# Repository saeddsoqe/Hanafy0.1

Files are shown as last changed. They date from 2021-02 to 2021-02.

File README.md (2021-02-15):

# Hanafy 0.1

H 0.1
The H series is an open-source educational programmable circuit board powered by regular alkaline batteries. The H series is a safe, easy-to-use, platform for building projects in school at home or for fun

In this repo:
Schematic 
Layout
3D model
Bill Of Material
Graber file

Features
Version: H-0.1
ARM architecture.
ESP32 Dev Board. Dual core processor.  
Dimensions: 7.4cm * 7.2cm * 2cm

Built-in modules:
LDR (light sensor)
Push button *4
I/O pins *10
ON/OFF switch
RGB 
4 push buttons

Supports:
DC motor *2
Stepper motor *1

Power Supply: 
1.5V *4

Development environment:Block programming

Release date:March 2021
    Autodesk Eagle for schematic and layout design, and Fusion 360 for the 3D design.  

// Extra info
Supports:
  Wifi*
  Bluetooth*
  Servo motors 1
  They are connected with a pull up resistor*
version02: 
IoT capabilites

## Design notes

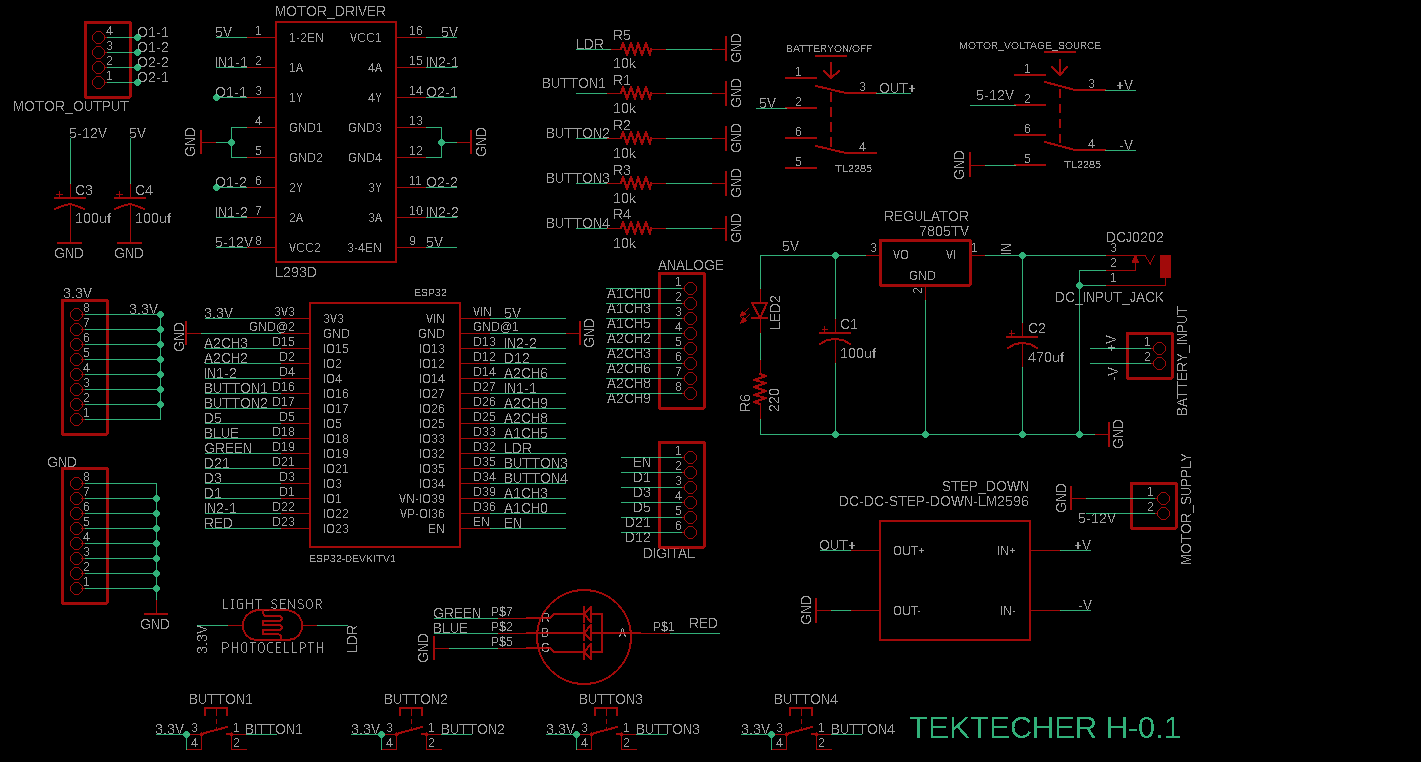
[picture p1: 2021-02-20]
PICs/schamatic.png

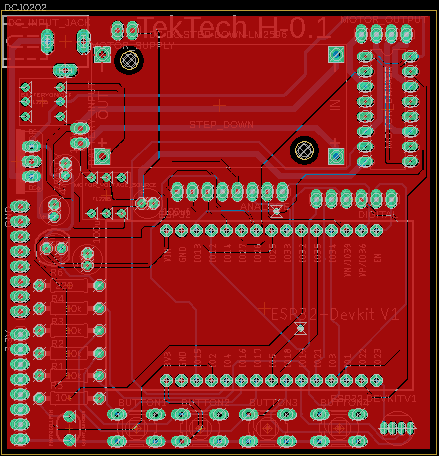
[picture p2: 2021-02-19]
PICs/fullLayout01.png

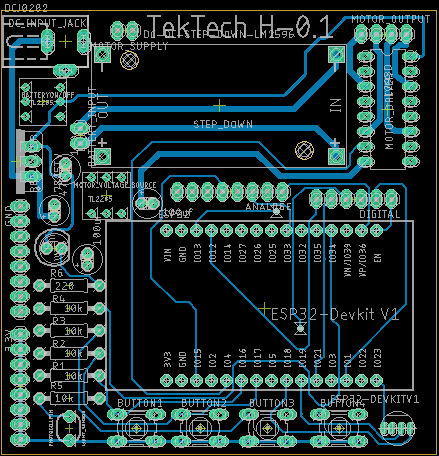
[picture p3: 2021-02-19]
PICs/fullLayout02.png

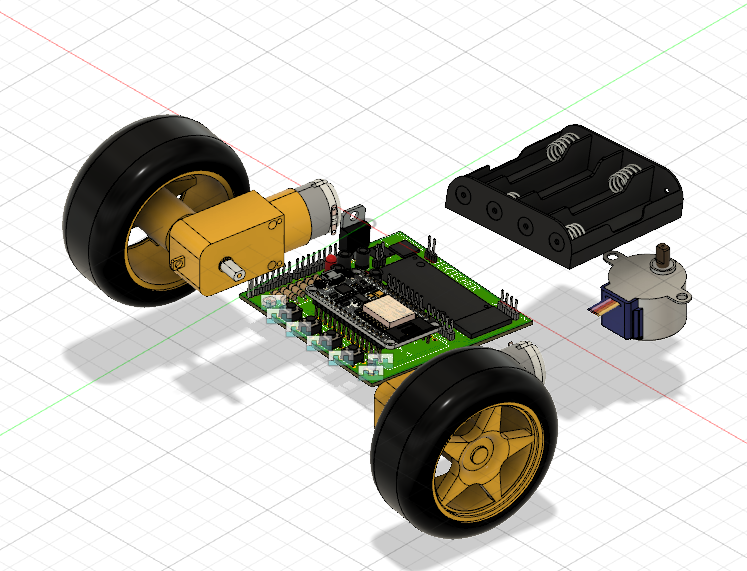
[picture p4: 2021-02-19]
PICs/Capture.PNG

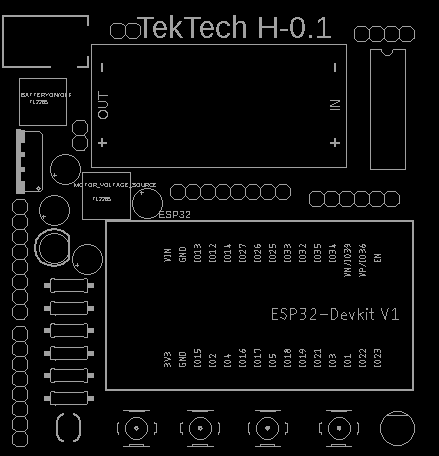
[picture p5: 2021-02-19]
PICs/LAYOUT_v02.png

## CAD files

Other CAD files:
Board/3D Model/assembly v3.f3z

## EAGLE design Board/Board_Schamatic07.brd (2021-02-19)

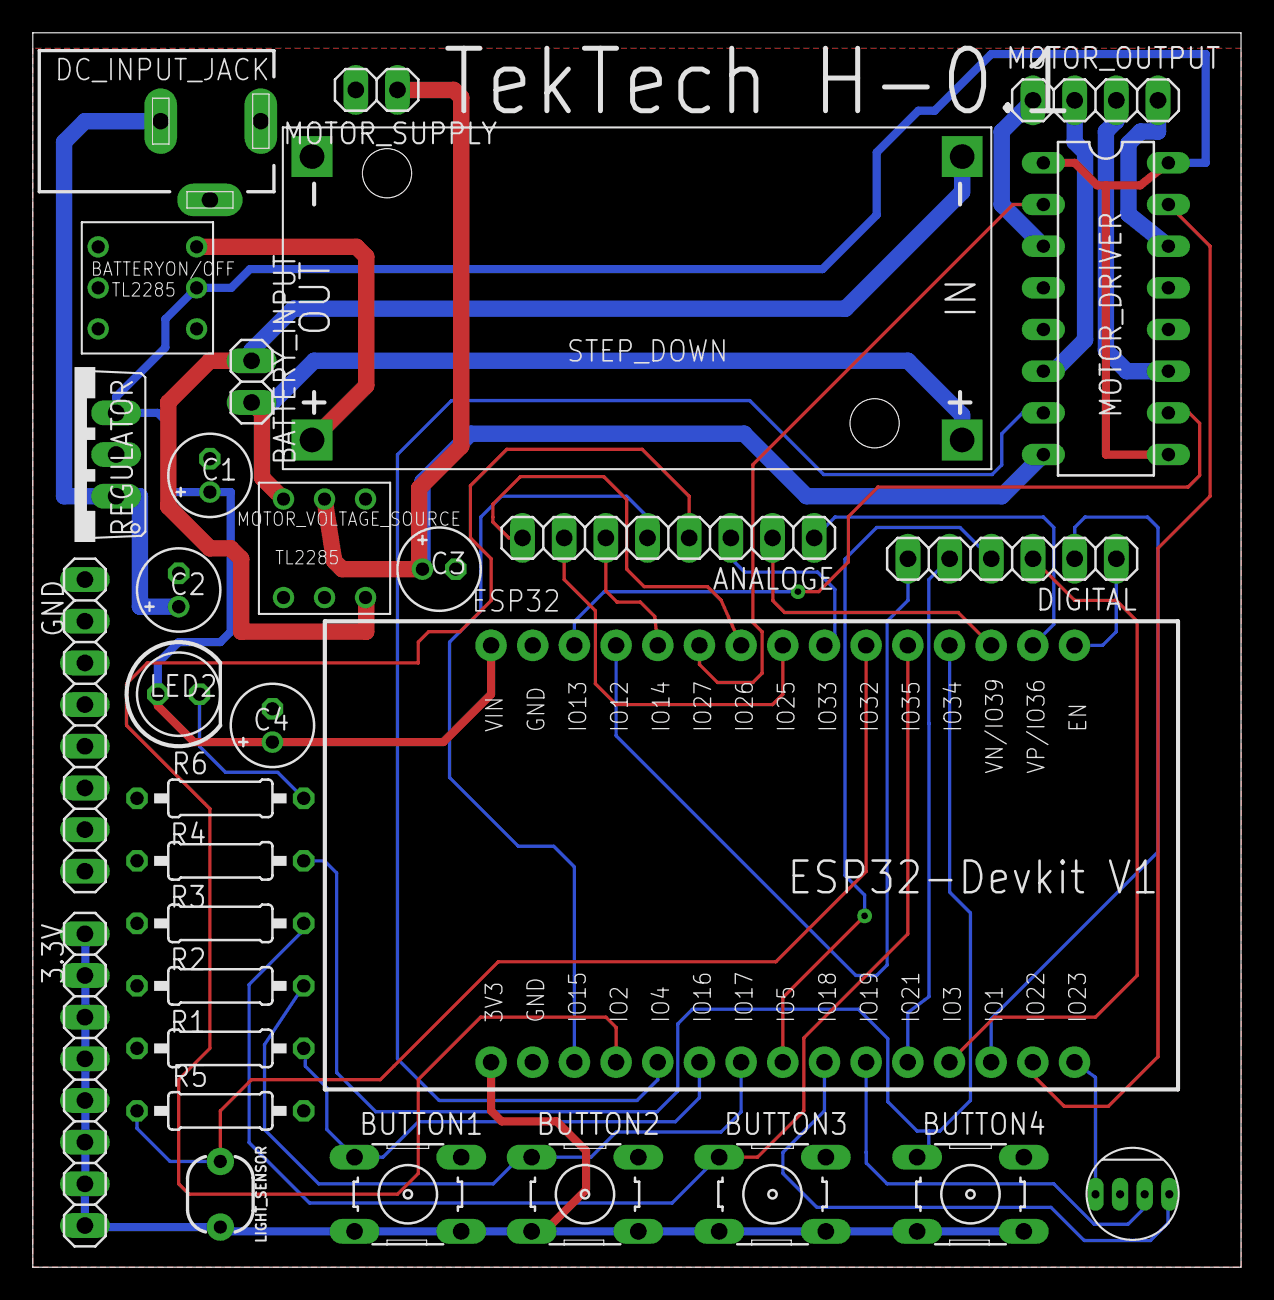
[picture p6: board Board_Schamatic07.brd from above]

Board: 2 copper layers, 73.6 x 75.2 mm, 31 parts (0 on the bottom side), 39 nets.

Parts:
3.3V: 1X08
ANALOGE: 1X08
BATTERYON/OFF: TL2285; TL2285_PCB
BATTERY_INPUT: 1X02
BUTTON1, BUTTON2, BUTTON3, BUTTON4: B3F-10XX
C1, C3, C4: 100uf; E2-5
C2: 470uf; E2-5
DC_INPUT_JACK: DCJ0202
DIGITAL: 1X06
ESP32: ESP32DEVKITV1; ESP32-DEVKITV1
GND: 1X08
LED2: LED5MM
LIGHT_SENSOR: PHOTOCELLPTH; PHOTOCELL
MOTOR_DRIVER: L293D; DIL16
MOTOR_OUTPUT: 1X04
MOTOR_SUPPLY: 1X02
MOTOR_VOLTAGE_SOURCE: TL2285; TL2285_PCB
R1, R2, R3, R4, R5: 10k; 0207/10
R6: 220; 0207/10
REGULATOR: 7805TV; TO220V
RGB: LED-4_PIN
STEP_DOWN: DC-DC-STEP-DOWN-LM2596

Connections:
3.3V: 3.3V.1, 3.3V.2, 3.3V.3, 3.3V.4, 3.3V.5, 3.3V.6, 3.3V.7, 3.3V.8, BUTTON1.3, BUTTON1.4, BUTTON2.3, BUTTON2.4, BUTTON3.3, BUTTON3.4, BUTTON4.3, BUTTON4.4, ESP32.3V3, LIGHT_SENSOR.2
5-12V: C3.+, MOTOR_DRIVER.8, MOTOR_SUPPLY.2, MOTOR_VOLTAGE_SOURCE.2
5V: BATTERYON/OFF.2, C1.+, C4.+, ESP32.VIN, LED2.A, MOTOR_DRIVER.1, MOTOR_DRIVER.9, MOTOR_DRIVER.16, REGULATOR.3
+V: BATTERY_INPUT.1, MOTOR_VOLTAGE_SOURCE.3, STEP_DOWN.IN+
-V: BATTERY_INPUT.2, MOTOR_VOLTAGE_SOURCE.4, STEP_DOWN.IN-
A1CH0: ANALOGE.1, ESP32.D36
A1CH3: ANALOGE.2, ESP32.D39
A1CH5: ANALOGE.3, ESP32.D33
A2CH2: ANALOGE.4, ESP32.D2
A2CH3: ANALOGE.5, ESP32.D15
A2CH6: ANALOGE.6, ESP32.D14
A2CH8: ANALOGE.7, ESP32.D25
A2CH9: ANALOGE.8, ESP32.D26
BLUE: ESP32.D18, RGB.P$2
D1: DIGITAL.2, ESP32.D1
D3: DIGITAL.3, ESP32.D3
D5: DIGITAL.4, ESP32.D5
D12: DIGITAL.6, ESP32.D12
D21: DIGITAL.5, ESP32.D21
EN: DIGITAL.1, ESP32.EN
GND: C1.-, C2.-, C3.-, C4.-, DC_INPUT_JACK.1, DC_INPUT_JACK.2, ESP32.GND@1, ESP32.GND@2, GND.1, GND.2, GND.3, GND.4, GND.5, GND.6, GND.7, GND.8, MOTOR_DRIVER.4, MOTOR_DRIVER.5, MOTOR_DRIVER.12, MOTOR_DRIVER.13, MOTOR_SUPPLY.1, MOTOR_VOLTAGE_SOURCE.5, R1.2, R2.2, R3.2, R4.2, R5.2, R6.1, REGULATOR.2, RGB.P$5, STEP_DOWN.OUT-
GREEN: ESP32.D19, RGB.P$7
IN: C2.+, DC_INPUT_JACK.3, REGULATOR.1
IN1-1: ESP32.D27, MOTOR_DRIVER.2
IN1-2: ESP32.D4, MOTOR_DRIVER.7
IN2-1: ESP32.D22, MOTOR_DRIVER.15
IN2-2: ESP32.D13, MOTOR_DRIVER.10
unnamed: BATTERYON/OFF.3, STEP_DOWN.OUT+
unnamed: LED2.K, R6.2
unnamed: BUTTON3.1, ESP32.D35, R3.1
unnamed: BUTTON4.1, ESP32.D34, R4.1
unnamed: ESP32.D32, LIGHT_SENSOR.1, R5.1
unnamed: BUTTON1.1, ESP32.D16, R1.1
unnamed: BUTTON2.1, ESP32.D17, R2.1
O1-1: MOTOR_DRIVER.3, MOTOR_OUTPUT.4
O1-2: MOTOR_DRIVER.6, MOTOR_OUTPUT.3
O2-1: MOTOR_DRIVER.14, MOTOR_OUTPUT.1
O2-2: MOTOR_DRIVER.11, MOTOR_OUTPUT.2
RED: ESP32.D23, RGB.P$1

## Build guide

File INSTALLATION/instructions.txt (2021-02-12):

Download and install Microblocks. 
------------------------------------------------------------------------
FOR WINDOWS 
1- Run microBlocks setup.exe 
2- MicroBlocks can be used in your browser 
https://microblocks.fun/run/microblocks.html
3- Or you cand download it as extenstion for Chrome from here 
https://chrome.google.com/webstore/detail/microblocks/cbmcbhgijipgdmlnieolilhghfmnngbb?authuser=0 
4-On some systems, you may need to install a serial driver. 
Depending on the USB-serial chip on your board you may need one of these:
   1-(CH340G driver) https://github.com/nodemcu/nodemcu-devkit/tree/master/Drivers 
   2-(Silcon Labs CP210x driver)https://www.silabs.com/products/development-tools/software/usb-to-uart-bridge-vcp-drivers

For MAC
On Mac OS, you need to confirm that MicroBlocks was downloaded from the internet the first time you run it.
1-Right-click on MicroBlocks.app and select "Open" from the menu:
*put photo*
2-Then click the "Open" button in the confirmation dialog:
*put photo* 
3-The dialog box will close. Now, double-click on MicroBlocks.app to open it.

FOR LINUX
On Linux systems, users don’t have access to the USB serial port by default. To fix that, just add yourself to 
the "dialout" group by running this in a terminal:
sudo usermod -G dialout -a `whoami`
Log out and back in to make the change take effect. You should see "dialout" when you list your groups.

Installing MicroBlocks Firmware
--------------------------------------------------------------------
To install the MicroBlocks firmware on an TIK TECH Board,
1-launch MicroBlocks and plug in the board. From the MicroBlocks (gear) menu, select "install firmware on board":
*put photo*
2-Then select "ESP32":
*put photo*
3-As the firmware loads, you will see a progress screen:
*put photo*
4-Once the firmware is installed, a green circle should appear to show that the board is connected.
*put photo*
That may take a few seconds. In rare cases you may need to disconnect and reconnect the board.

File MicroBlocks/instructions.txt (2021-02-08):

This the MicroBlocks for windows you can find Mac or a browser version  

follow the instruction in this page to download, install and use Microblocks 
http://microblocks.fun/download

this the Microblocks home page 
http://microblocks.fun/

you can find any informations in Microblocks wiki in this link 
https://wiki.microblocks.fun/

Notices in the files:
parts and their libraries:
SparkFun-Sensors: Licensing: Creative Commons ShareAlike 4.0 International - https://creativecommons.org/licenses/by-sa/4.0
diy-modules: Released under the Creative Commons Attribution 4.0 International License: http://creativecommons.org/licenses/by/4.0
